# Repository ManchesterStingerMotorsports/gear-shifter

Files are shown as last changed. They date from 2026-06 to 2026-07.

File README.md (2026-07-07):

# Gear Shifter

ESP-IDF firmware and bench-test projects for the Manchester Stinger Motorsports electronic gear shifter controller.

The repository now contains four standalone ESP32-S3 projects:

```text
gear-shifter/
  production_firmware/             Production shifter firmware
  can_test_firmware/                Bench test: CAN/TWAI test scaffold
  button_test_firmware/            Bench test: buttons, LEDs, and low ESC torque
  encoder_position_test_firmware/  Bench test: print AMT20 encoder position
  Hardware/                        KiCad hardware files
  ESC Settings/                    ESC configuration files
  Archive Python Code/             Earlier prototype scripts
```

There is intentionally no ESP-IDF project at the repository root. Open/build one of the firmware folders directly.

## Production Firmware

Project folder:

```text
production_firmware/
```

Build:

```powershell
cd C:\Users\james\FS\gear-shifter\production_firmware
idf.py build
```

Flash:

```powershell
idf.py -p COMx flash monitor
```

Current behavior:

- starts the shifter task and a placeholder CAN task
- reads shift inputs from GPIO
- rejects shifts that would leave the valid gear range
- uses the latest CAN task output during pre-check: neutral position sensor first, then ECU gear when the car is moving
- checks the encoder before commanding the ESC
- commands the ESC for the requested shift after safety checks pass
- stops the ESC when the encoder reaches the calibrated target, an encoder read fails, or the shift timeout expires
- tracks the internal gear state through neutral, 1st, 2nd, 3rd, 4th, and 5th
- prints encoder position continuously while idle and during shift movement

Production pin, timing, and calibration constants live in:

```text
production_firmware/main/config.hpp
```

Production source layout:

```text
production_firmware/main/
  config.hpp
  main.cpp
  encoder/             AMT20 encoder driver
  esc/                 ESC PWM driver
  interrupts/          GPIO ISR/input latch code
  tasks/
    can_task/          CAN output placeholder/status
    shifter_task/      Main shifter control logic
```

Current values:

```cpp
static constexpr bool STANDALONE_TESTING = true;
static constexpr int8_t STANDALONE_INITIAL_GEAR = 2;
static constexpr float SHIFT_UP_TORQUE = 0.4f;
static constexpr float SHIFT_DOWN_TORQUE = -0.4f;
static constexpr float SHIFT_1_TO_NEUTRAL_TORQUE = SHIFT_UP_TORQUE;
static constexpr float SHIFT_NEUTRAL_TO_1_TORQUE = SHIFT_DOWN_TORQUE;
static constexpr uint16_t BASE_POSITION = 2840;
static constexpr uint16_t SHIFT_UP_STOP_POSITION = 2639;
static constexpr uint16_t SHIFT_DOWN_STOP_POSITION = 3039;
static constexpr uint16_t SHIFT_1_TO_NEUTRAL_STOP_POSITION = BASE_POSITION;
static constexpr uint16_t SHIFT_NEUTRAL_TO_1_STOP_POSITION = SHIFT_DOWN_STOP_POSITION;
static constexpr uint16_t SHIFT_POSITION_TOLERANCE = 20;
```

## Button And ESC Test

Project folder:

```text
button_test_firmware/
```

Behavior:

- reads UP, DOWN, and NEUTRAL as active-low inputs
- high impedance reads as released using the internal pull-up
- GND reads as pressed
- prints the button state to serial whenever it changes
- mirrors the debounced button states on the UP, DOWN, and NEUTRAL LEDs
- commands low positive ESC torque while UP is pressed
- commands low negative ESC torque while DOWN is pressed
- sends neutral ESC torque when neither or both shift directions are pressed

Constants live in:

```text
button_test_firmware/main/main.cpp
```

## Encoder Position Test

Project folder:

```text
encoder_position_test_firmware/
```

Behavior:

- repeatedly reads the AMT20 encoder over SPI
- prints the raw encoder position from `0` to `4095`

Constants live in:

```text
encoder_position_test_firmware/main/main.cpp
```

## CAN Test

Project folder:

```text
can_test_firmware/
```

Behavior:

- intentionally blank scaffold for CAN/TWAI bench testing
- builds with the same reusable `MSM_CAN` helper used by production firmware

Constants and test logic can be added in:

```text
can_test_firmware/main/main.cpp
```

## Pin Map

| Function | ESP32-S3 GPIO |
| --- | ---: |
| ESC PWM | GPIO 9 |
| Encoder CS | GPIO 10 |
| Encoder MOSI | GPIO 11 |
| Encoder SCLK | GPIO 12 |
| Encoder MISO | GPIO 13 |
| Shift up input | GPIO 48 |
| Shift down input | GPIO 45 |
| Shift neutral input | GPIO 47 |
| Shift up LED | GPIO 7 |
| Shift down LED | GPIO 6 |
| Shift neutral LED | GPIO 5 |
| CAN RX | GPIO 2 |
| CAN TX | GPIO 1 |

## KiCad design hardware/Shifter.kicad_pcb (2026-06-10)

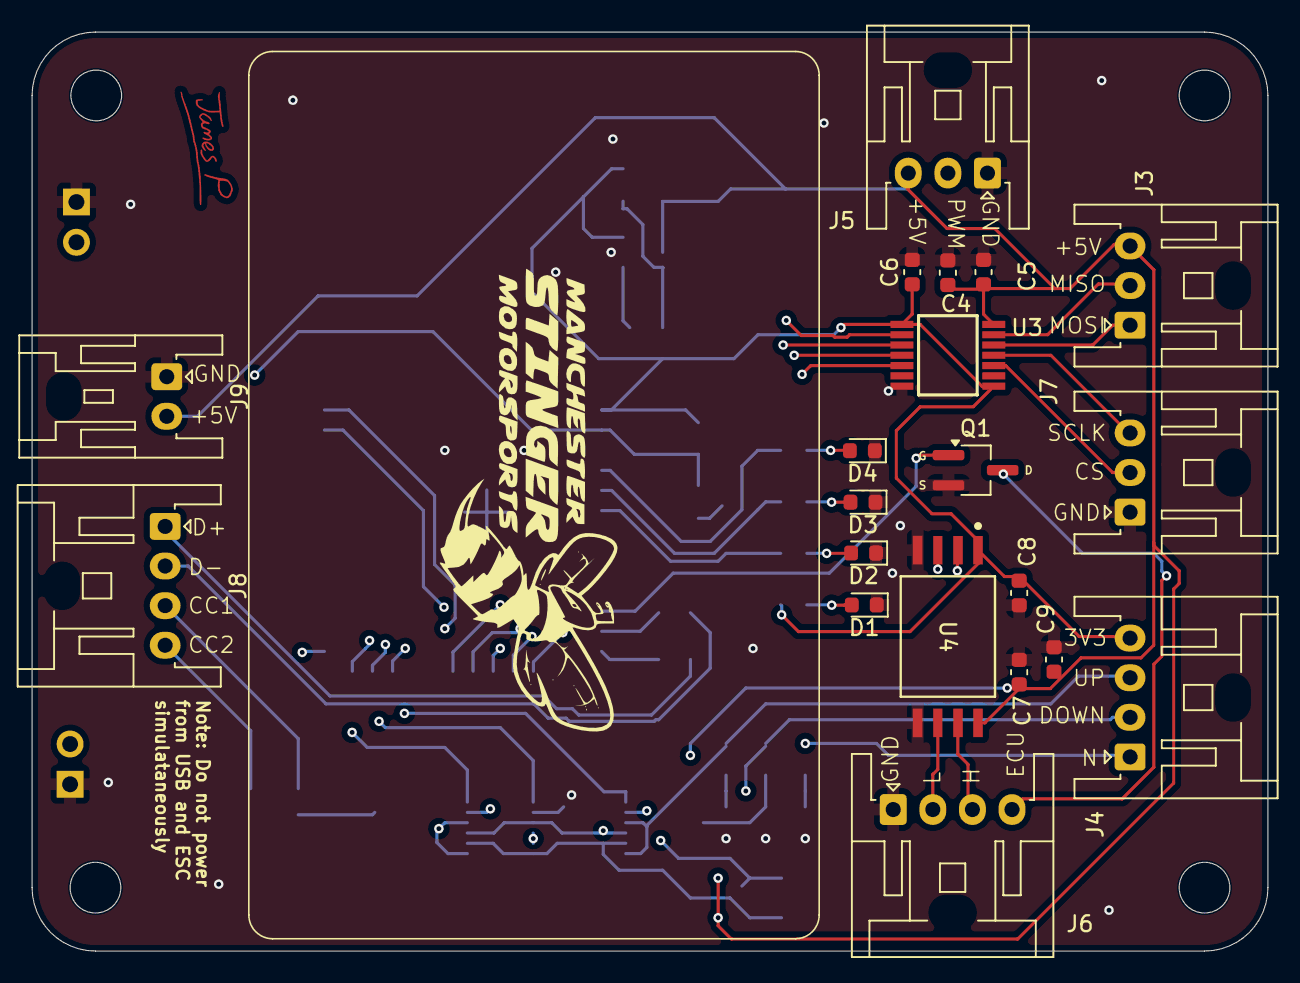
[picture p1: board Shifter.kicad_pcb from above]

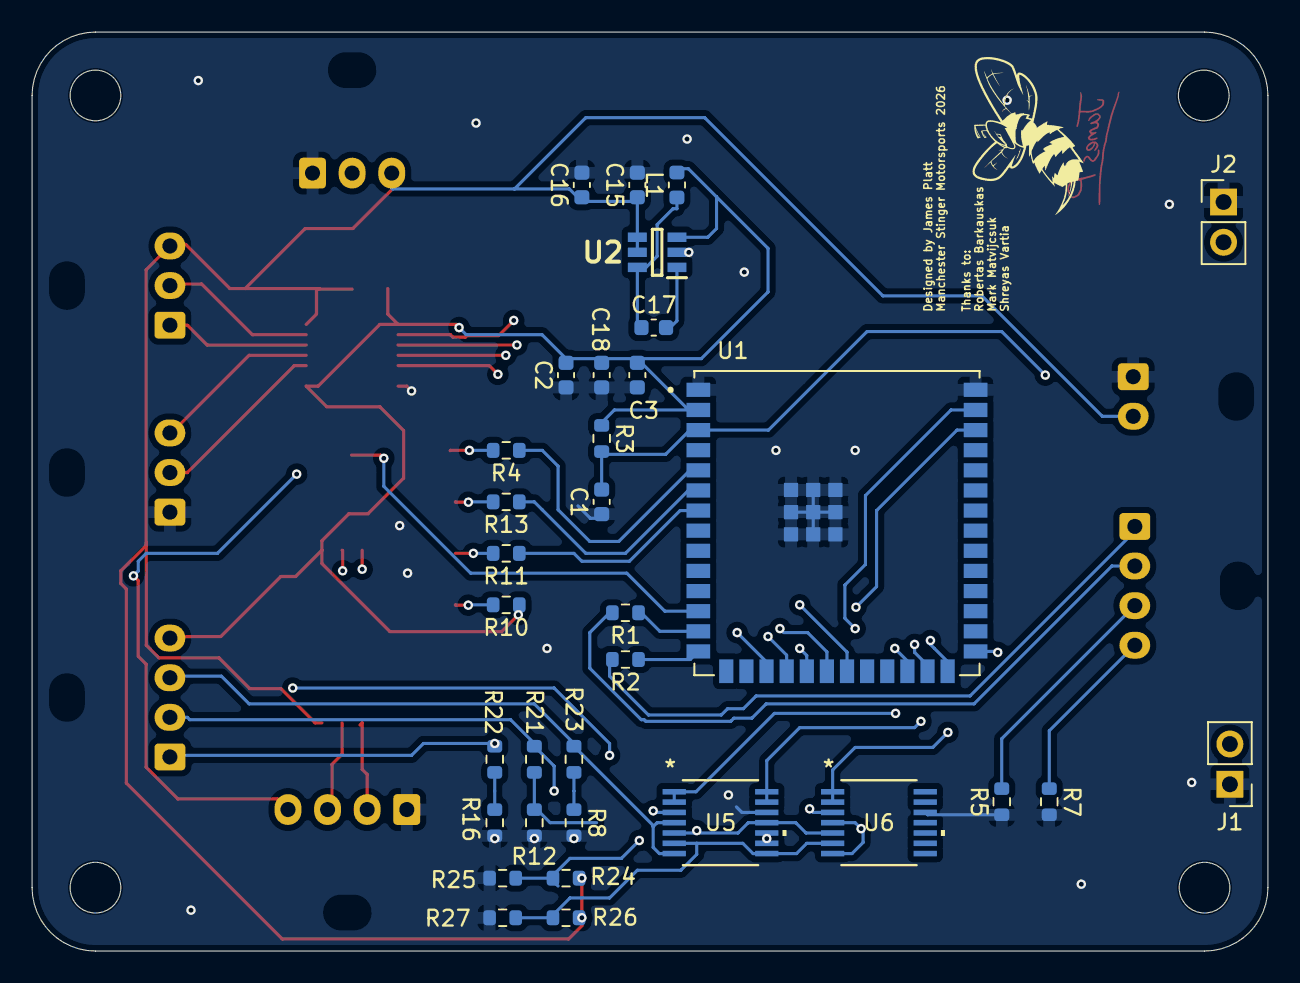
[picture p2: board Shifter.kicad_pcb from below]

Board: 4 copper layers, 78.0 x 58.0 mm, 53 parts (33 on the bottom side), 46 nets.

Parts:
C1, C5: 1u; C_0603_1608Metric
C2, C18: 10u; C_0603_1608Metric
C3, C4, C6, C7, C8: 0.1u; C_0603_1608Metric
C9: 4.7u; C_0603_1608Metric
C15: 2.2u; C_0603_1608Metric
C16, C17: 100n; C_0603_1608Metric
D1, D4: RED LED; LED_0603_1608Metric
D2: GREEN LED; LED_0603_1608Metric
D3: BLUE LED; LED_0603_1608Metric
J1: RST; PinHeader_1x02_P2.54mm_Vertical
J2: BSEL; PinHeader_1x02_P2.54mm_Vertical
J3, J5, J7: S03B-XASK-1; JST_XA_S03B-XASK-1_1x03_P2.50mm_Horizontal
J4, J6, J8: SO4B-XASK-1; JST_XA_S04B-XASK-1_1x04_P2.50mm_Horizontal
J9: Conn_01x02; JST_XA_S02B-XASK-1_1x02_P2.50mm_Horizontal
L1: 2.2u; L_0603_1608Metric
Q1: BSS205N; MOSFET_Single_SOT-23
R1, R2: 27; R_0603_1608Metric
R3, R8, R12, R16, R25, R27: 10k; R_0603_1608Metric
R4, R10: 270R; R_0603_1608Metric
R5, R7: 5k1; R_0603_1608Metric
R11: 220R; R_0603_1608Metric
R13: 100R; R_0603_1608Metric
R21, R22, R23: 180; R_0603_1608Metric
R24: 5k6; R_0603_1608Metric
R26: 12k; R_0603_1608Metric
U1: ESP32-S3-WROOM-1U-N4R2; XCVR_ESP32-S3-WROOM-1U-N4R2
U2: LMR50410Y3FQDBVRQ1; SOT95P280X145-6N
U3: MAX3390EEUD_T; SOP65P640X110-14N
U4: ISO1042BQDWVQ1; DWV0008A-MFG
U5, U6: TLV1704; PW14_TEX

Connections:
2.5V Ref: R26.2, R27.1, U5.6 (-), U5.8 (-), U6.6 (-)
3.5V Ref: R24.2, R25.1, U5.5 (+), U5.11 (+), U6.5 (+)
+3V3: C2.2, C3.2, C6.1, C8.2, C18.1, J4.4, L1.2, R3.1, R10.1, U1.2 (3V3), U2.3 (FB), U3.1 (VL), U3.8 (~THREE-STATE), U4.1 (VCC1)
+5V: C4.1, C5.1, C7.2, C9.2, C15.1, C16.1, J3.3, J5.3, J9.2, R24.1, R26.1, U2.4 (EN), U2.5 (VIN), U3.14 (VCC), U4.8 (VCC2), U5.3 (V+), U6.3 (V+)
CAND: U1.39 (IO1), U4.2 (TXD)
CANH: J6.3, U4.7 (CANH)
CANL: J6.2, U4.6 (CANL)
CANR: U1.38 (IO2), U4.3 (RXD)
CS: U1.18 (IO10), U3.5 (I_VL4)
DOWN: U1.25 (IO48), U5.13, U5.14
DOWN_LED: R13.1, U1.6 (IO6)
ECU: J6.4, Q1.3 (D)
E_CS: J7.2, U3.10 (O_VCC4)
E_MISO: J3.2, U3.13 (I_VCC1)
E_MOSI: J3.1, U3.12 (O_VCC2)
E_SCLK: J7.3, U3.11 (O_VCC3)
FLATSHIFT: Q1.1 (G), U1.12 (IO8)
GND: C1.1, C2.1, C3.1, C4.2, C5.2, C6.2, C7.1, C8.1, C9.1, C15.2, C16.2, C18.2, D1.1 (K), D2.1 (K), D3.1 (K), D4.1 (K), J1.1, J2.1, J5.1, J6.1, J7.1, J9.1, Q1.2 (S), R5.1, R7.2, R8.2, R12.2, R16.2, R25.2, R27.2, U1.1 (GND), U1.40 (GND__1), U1.41_1 (GND__2), U1.41_2 (GND__3), U1.41_3 (GND__4), U1.41_4 (GND__5), U1.41_5 (GND__6), U1.41_6 (GND__7), U1.41_7 (GND__8), U1.41_8 (GND__9), U1.41_9 (GND__10), U2.2 (GND), U3.7 (GND), U4.4 (GND1), U4.5 (GND2), U5.12 (V-), U6.12 (V-)
MISO: U1.21 (IO13), U3.2 (O_VL1)
MOSI: U1.19 (IO11), U3.3 (I_VL2)
Main_Reset: C1.2, J1.2, R3.2, U1.3 (EN)
NEUTRAL: U1.26 (IO45), U6.1, U6.2
NEUTRAL_LED: R4.1, U1.5 (IO5)
unnamed: D1.2 (A), R10.2
unnamed: D2.2 (A), R11.2
unnamed: D3.2 (A), R13.2
unnamed: D4.2 (A), R4.2
unnamed: J2.2, U1.27 (IO0)
unnamed: J8.3, R5.2
unnamed: J8.4, R7.1
unnamed: R1.1, U1.13 (IO19)
unnamed: R2.1, U1.14 (IO20)
unnamed: C17.2, U2.1 (CB)
unnamed: C17.1, L1.1, U2.6 (SW)
unnamed: R8.1, R23.2
unnamed: R12.1, R21.2
unnamed: R16.1, R22.2
PWM: J5.2, U1.17 (IO9)
SCLK: U1.20 (IO12), U3.4 (I_VL3)
SHIFT_DOWN: J4.2, R21.1, U5.9 (+), U5.10 (-)
SHIFT_NEUTRAL: J4.1, R22.1, U6.4 (-), U6.7 (+)
SHIFT_UP: J4.3, R23.1, U5.4 (-), U5.7 (+)
UP: U1.24 (IO47), U5.1, U5.2
UP_LED: R11.1, U1.7 (IO7)
USBD+: J8.1, R2.2
USBD-: J8.2, R1.2

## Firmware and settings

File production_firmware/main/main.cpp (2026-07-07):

/**
Gear Shifter Code 
For any questions contact James Platt

The design philosophy prioritises safety. At the time of writing this software my feeling was the best way of doing 
this was for the shifting events (i.e UP, DOWN, NEUTRAL) to have their own dedicated fully blocking ISRs.
In these ISRs any additional interrupts would be IGNORED and freertos task switching would be DISABLED.
It would have completely "locked" the autoshifter into the shift event until either:
    - The "shifted" position is reached (i.e succesful shift has occured)
    - A timeout occurs. This is logged as an error, but not treated as a hard fail.

I did not end up doing it this way because the shift itself is a relatively long mechanical event, and ISRs are not
really the right place to sit and wait for mechanical things to happen. The bigger problem is
timing/watchdog/driver behaviour: a long ISR can upset software timers, watchdog
servicing, and any ESP-IDF/FreeRTOS driver code that expects the RTOS and interrupts to still be alive.

The approach used here is therefore slightly different. The shifting events are still detected by their own dedicated
GPIO ISRs, but these ISRs do NOT actually do the shift. They only latch the first shift request, disable any more shift
input interrupts, and wake the high priority shifter task.

The shifter task then effectively "owns" the autoshifter until either:
    - The "shifted" position is reached (i.e succesful shift has occured)
    - A timeout occurs. This is logged as an error, but not treated as a hard fail.

During this shift window any additional shift inputs are IGNORED because the shift GPIO interrupts are disabled.
The shifter task is also created at the highest priority and the core actuation window is written to be
non-blocking, so lower priority tasks should not randomly run in the middle of a shift.

When a shift event is detected (i.e user button input) a few safety checks are done before the ESC is commanded.
These are written to be as fast as possible without compromising on safety. Then the output PWM command to the ESC
is sent.

Some of the important safety checks are: 
    - the requested gear shift does not result in an out-of-range gear (i.e shifting into "6th")
    - the encoder can be read before the ESC is commanded
    
**/





//Esp logging library (a nicer way of "printing to serial" it allows you to specify different levels of importance e.g LOGW (warning) LOGE (error) LOGI (info)
#include "esp_log.h"

//freertos libraries for tasks
#include "freertos/FreeRTOS.h"                           
#include "freertos/task.h" 

#include "config.hpp"
#include "shifter_task.hpp"

//Logging is seperated by tags
static const char *TAG_SYS = "SYSTEM";

// Entry point
extern "C" void app_main(void)
{
    ESP_LOGI(TAG_SYS, "Creating tasks");

    BaseType_t ok;
    bool success = true;

    //highest priority.
    ok = xTaskCreatePinnedToCore(shifter_task,
                                 "shifter_task",
                                 config::SHIFTER_TASK_STACK_WORDS,
                                 nullptr,
                                 config::SHIFTER_TASK_PRIORITY,
                                 nullptr,
                                 config::CONTROL_CORE);
    if(ok != pdPASS){success = false;}
    
    // If task creation fails, the controller is in an unknown/partial startup
    // state. Stop interrupts and park forever instead of running without one of
    // the safety-critical tasks. (Hard fail)

    if(!success){
        ESP_LOGE(TAG_SYS, "Task creation failed!");
        taskDISABLE_INTERRUPTS();
        for (;;);
    }

    // app_main() has done its job once the tasks are alive. The tasks themselves
    // contain the arduino-style superloops that keep the application alive.
    ESP_LOGI(TAG_SYS, "Tasks created succesfully!");

    // Delete app_main task.
    vTaskDelete(NULL);
}

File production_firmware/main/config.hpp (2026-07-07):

#pragma once

#include <cstdint>

#include "driver/gpio.h"

#include "freertos/FreeRTOS.h"
#include "freertos/task.h"

namespace config
{
static constexpr bool STANDALONE_TESTING = true;
static constexpr int8_t STANDALONE_INITIAL_GEAR = 2;

// Keep the shifter actuation path on one core so priority, not cross-core
// scheduling, decides what can run during the shift actuation window.
static const BaseType_t CONTROL_CORE = 1;

static const UBaseType_t SHIFTER_TASK_PRIORITY = configMAX_PRIORITIES - 1;

static constexpr uint32_t SHIFTER_TASK_STACK_WORDS = 4096;

static constexpr gpio_num_t ESC_PWM_GPIO = GPIO_NUM_9;

static constexpr gpio_num_t SHIFT_UP_GPIO = GPIO_NUM_47;
static constexpr gpio_num_t SHIFT_DOWN_GPIO = GPIO_NUM_48;

static constexpr gpio_num_t UP_LED_GPIO = GPIO_NUM_7;
static constexpr gpio_num_t DOWN_LED_GPIO = GPIO_NUM_6;
static constexpr gpio_num_t NEUTRAL_LED_GPIO = GPIO_NUM_5;
static constexpr bool LED_ACTIVE_HIGH = true;

static constexpr uint32_t SHIFT_INPUT_RELEASE_DEBOUNCE_MS = 100;
static constexpr uint32_t SHIFT_INPUT_RELEASE_POLL_MS = 1;

static constexpr uint32_t SHIFT_ACTUATION_MS = 200;
static constexpr uint32_t AUTO_SHIFT_PERIOD_MS = 2000;

static constexpr float SHIFT_UP_TORQUE = 0.8f;
static constexpr float SHIFT_DOWN_TORQUE = -0.8f;
}

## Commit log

2025-11-03 Add Shifter Kicad Schem
    Added USB-C, Linear Batt->5V reg, Switching 5V->3V3 reg
    [Reference_import.kicad_pcb, Reference_import.kicad_sch, Shifter_demo.kicad_pcb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]
2025-11-03 Add Gear shifter code
    Duplicated from the sharepoint
2025-11-14 Create .gitignore for KiCad project files
    Added a .gitignore file to exclude KiCad temporary and backup files.
2025-11-15 Update Schematic
    Adds ESP32, CAN and basically everything...
    [Shifter_demo.kicad_sch]
2025-11-16 route it all and make minor schem mods
    [Shifter_demo.kicad_pcb, Shifter_demo.kicad_sch]
2025-11-19 Add SCS checks to Schematic and PCB
    [Shifter_demo.kicad_pcb, Shifter_demo.kicad_sch]
2026-04-15 Add ESP framework
    [Reference_import.kicad_pcb, Reference_import.kicad_sch, Shifter_demo.kicad_pcb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]
2026-04-15 add hardware
    [Shifter.kicad_pcb, Shifter.kicad_sch]
2026-04-16 Setup ISR framework
2026-04-17 ESC class
2026-04-18 add encoder stuff
2026-04-18 ecu gear count takes priority
2026-06-09 ready to go
    [Shifter.kicad_pcb, Shifter.kicad_sch]
2026-06-09 actually good to go
    [Shifter.kicad_pcb]
2026-06-10 add latest MSM_CAN
    [Shifter.kicad_pcb]
2026-07-07 minor changes
    [Shifter.kicad_sch]
